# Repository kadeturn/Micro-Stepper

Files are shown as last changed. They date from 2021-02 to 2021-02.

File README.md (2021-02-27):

# Micro Stepper

This repository contains work on various breakout boards for the micro linear stepper motors used in motorised mobile phone cameras.

These stepper motors are available in several variations from different Chinese suppliers.

Current and future CAD models for the stepper motors can be found [here](hw/cad).

All PCBs are created using KiCad Nightly builds.

---

## Micro Breakout

The first breakout board is based on [this](https://www.aliexpress.com/item/4000616045699.html?spm=a2g0s.12269583.0.0.51854815RwJf8O) stepper motor from Aliexpress.

Both the Model A and Model B variants work with this breakout (the only difference being their linear guide mounting features).
These motors can produce a force in the range of ~100-150gf, the main downside is that they have quite a bit of backlash.

<p align="center">
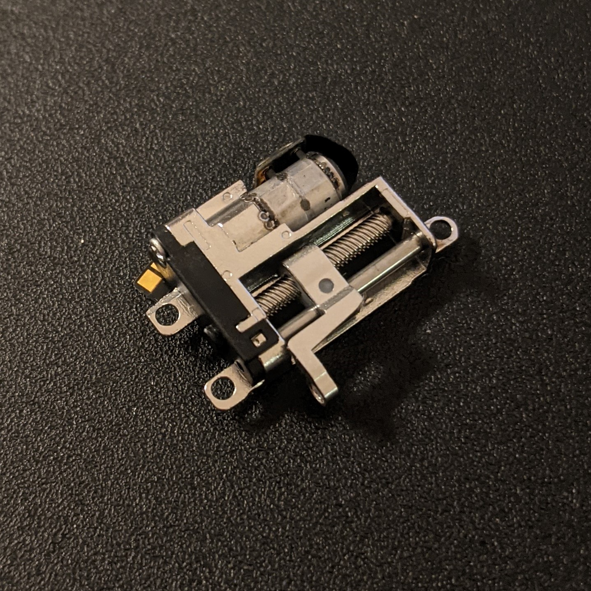
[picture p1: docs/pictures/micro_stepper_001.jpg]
  
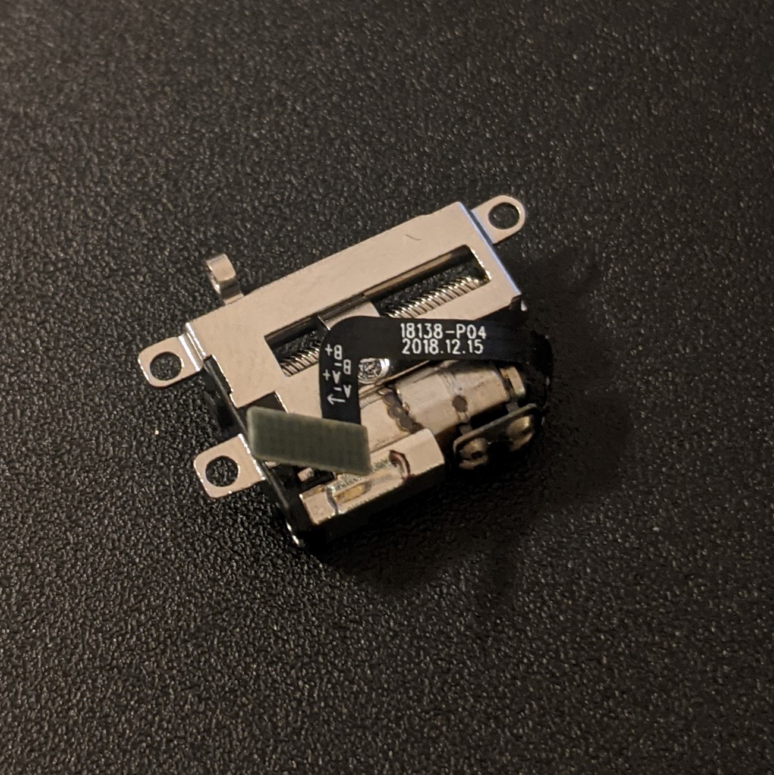
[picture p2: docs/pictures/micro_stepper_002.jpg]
  
</p>

The breakout uses the [Trinamic TMC2300](https://www.trinamic.com/products/integrated-circuits/details/tmc2300-la/) low voltage stepper motor driver. 

Both step/direction and UART based control are possible, with the latter enabling current sensing (useful for end stop detection).

The UART is single wire based, so an additional external resistor is required to split TX & RX out separately (more to come on that later).

<p align="center">
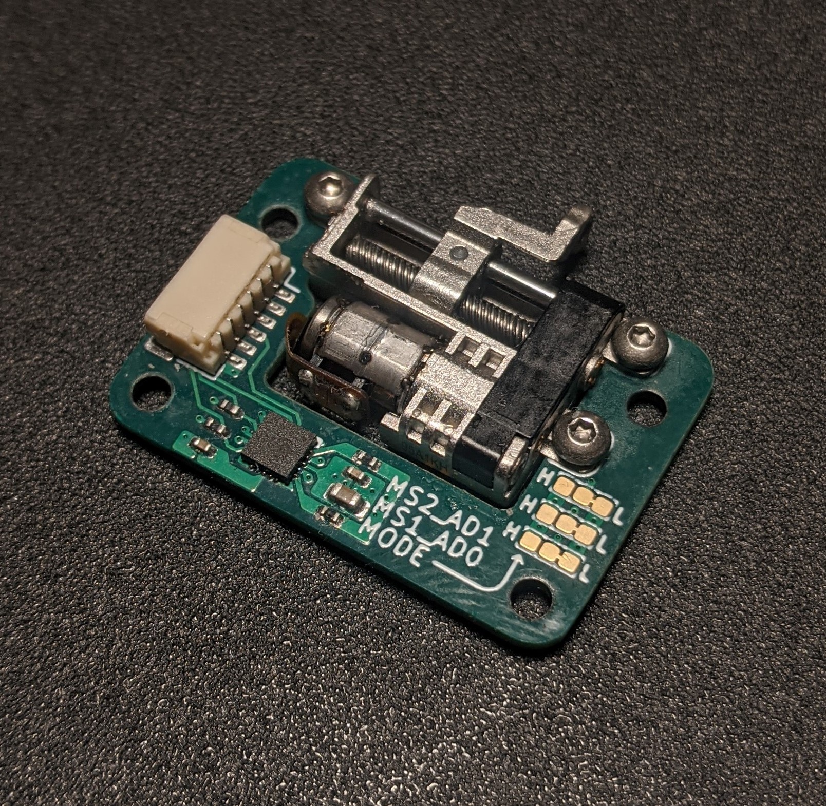
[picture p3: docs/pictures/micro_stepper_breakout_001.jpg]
  
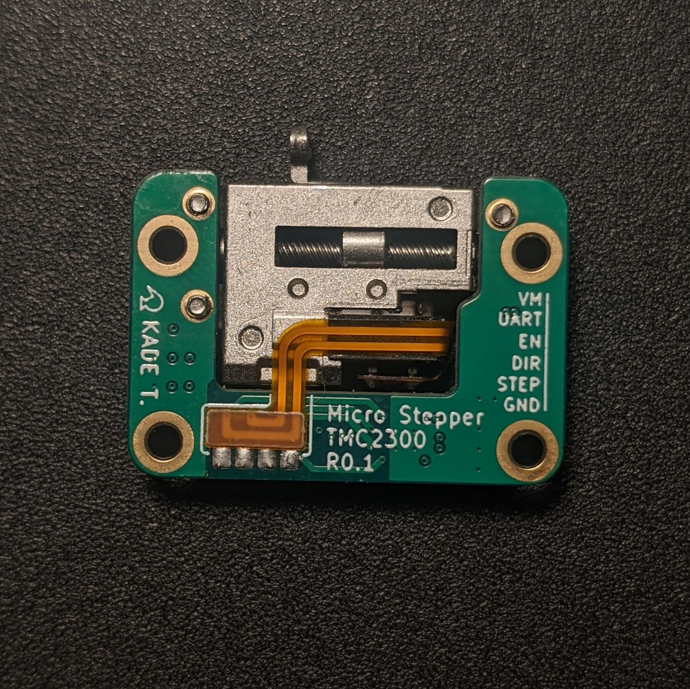
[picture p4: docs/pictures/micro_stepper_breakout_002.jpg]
  
</p>

KiCad and Gerber files are located [here](hw/micro_breakout_001).

---

## Micro Driver

The World's smallest stepper driver board (probably).

Based on the same TMC2300 stepper motor driver as used in the Micro Breakout. It's designed for use with any small low voltage stepper motor.

**The PCB is just 10.2mm x 6mm!!**

<p align="center">
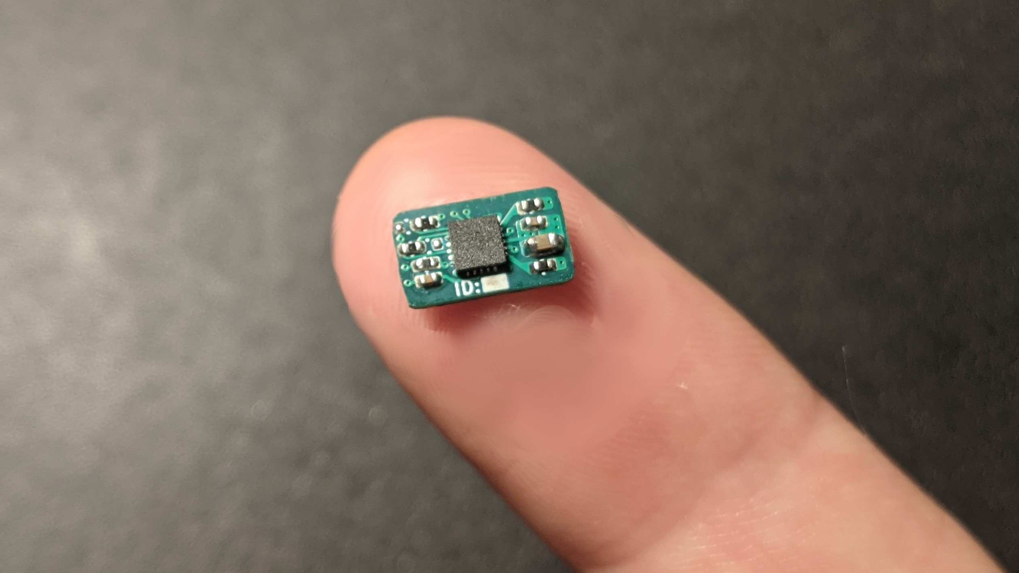
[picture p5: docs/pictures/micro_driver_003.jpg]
    
</p>

<p align="center">
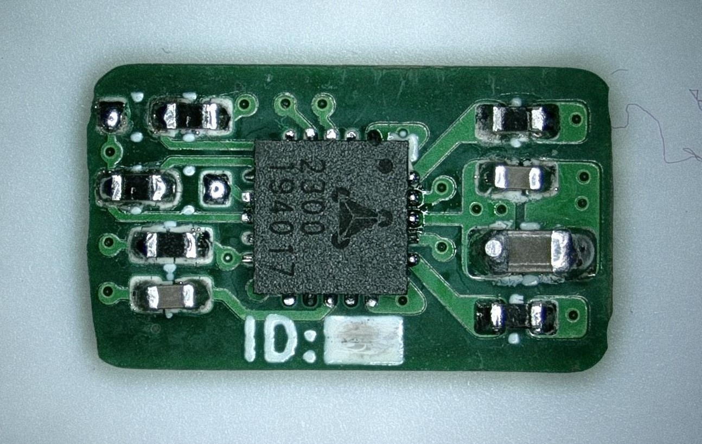
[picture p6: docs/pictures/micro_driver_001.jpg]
    
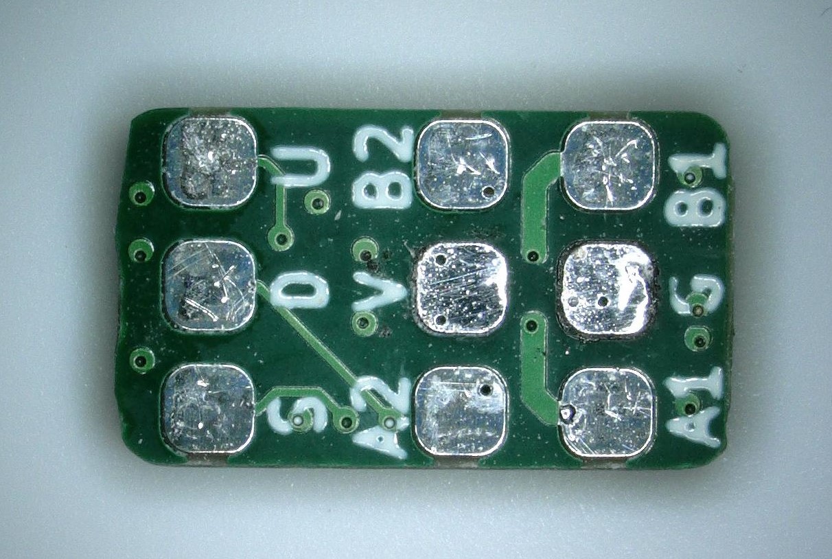
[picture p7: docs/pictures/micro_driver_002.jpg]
    
</p>

Due to a small issue with the enable pin always pulled low, and incorrect silkscreen, the files are currently not released (wait for rev002).

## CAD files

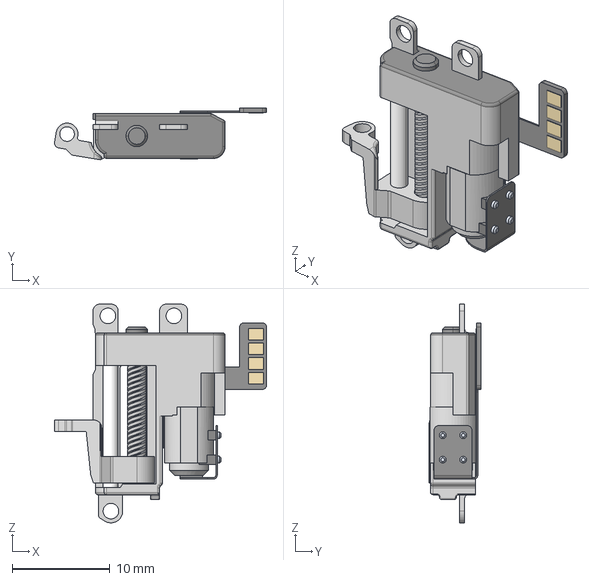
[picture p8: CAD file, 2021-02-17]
hw/cad/micro_stepper_asm.stp
21.7 x 5.29 x 22.4 mm
MICRO_STEPPER_BASE
STEPPER_SLIDER

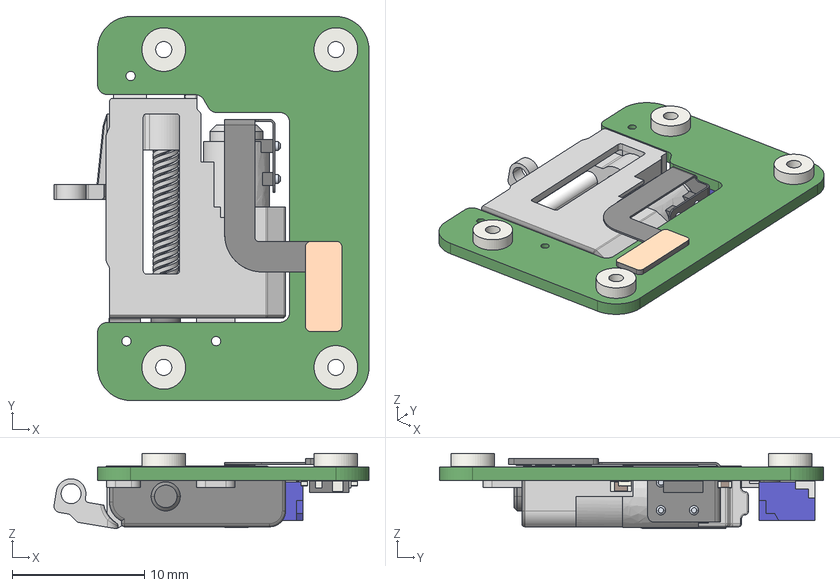
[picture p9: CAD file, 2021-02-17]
hw/micro_breakout_001/Export/micro_breakout_001.step
23.8 x 29.0 x 5.69 mm

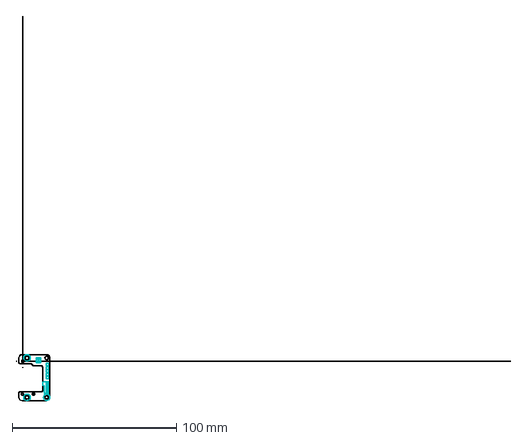
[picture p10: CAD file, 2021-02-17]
hw/micro_breakout_001/pcb_outline_001.dxf
301.0 x 234.0 mm

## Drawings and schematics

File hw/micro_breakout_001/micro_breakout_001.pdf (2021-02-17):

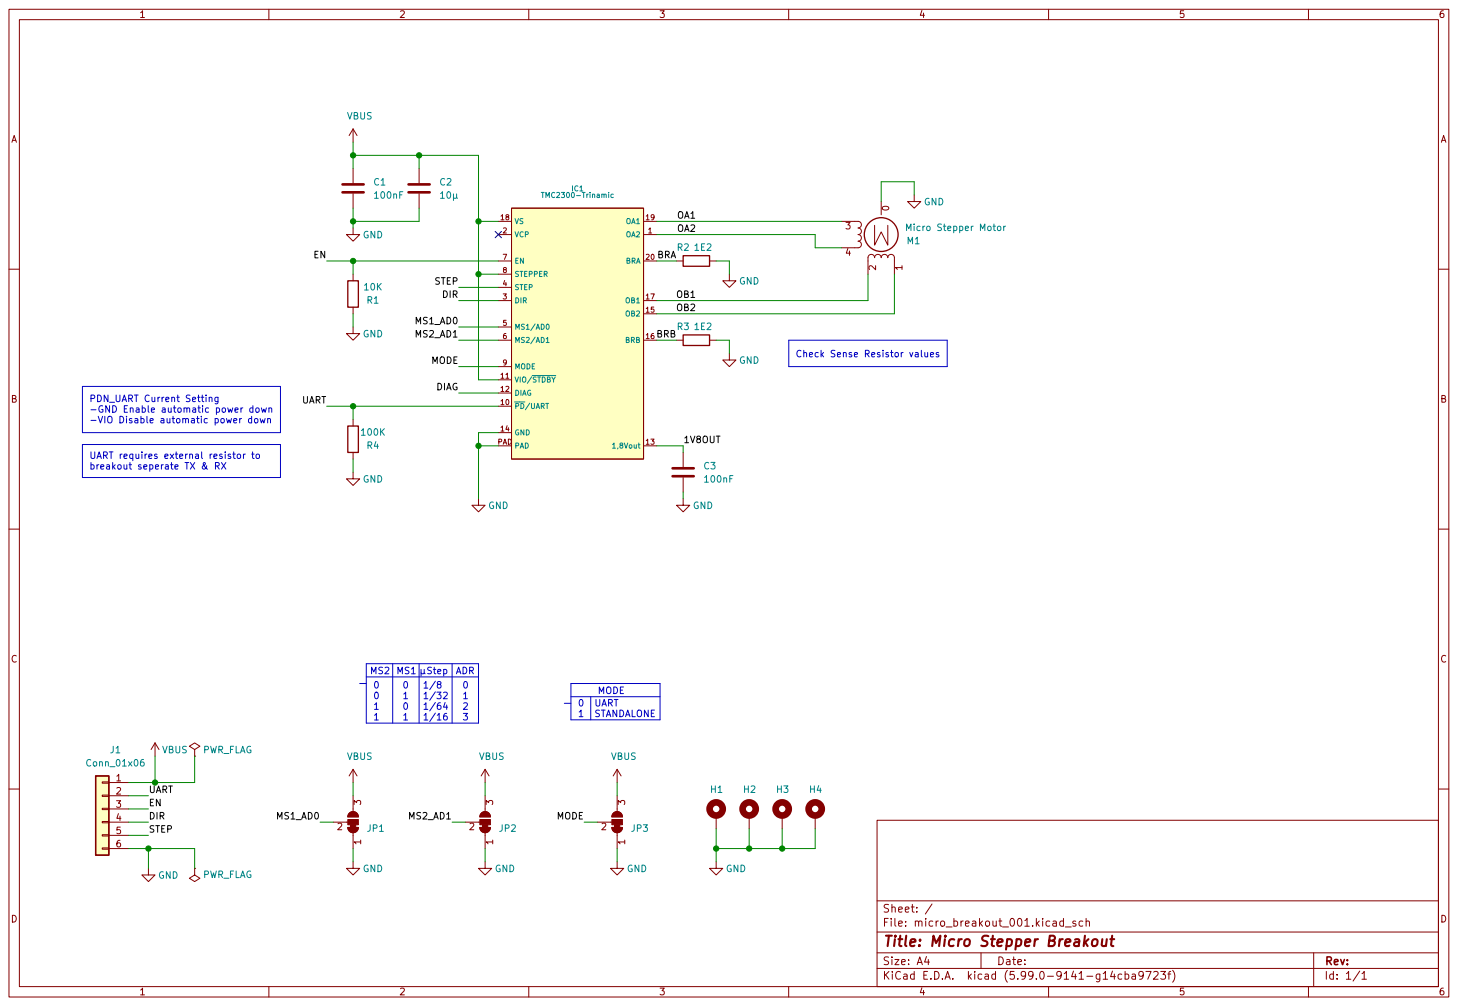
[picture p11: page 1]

OB2 MODE UART PDN_UART Current Setting

-GND Enable automatic power down

breakout seperate TX & RX

0 1 | UART STANDALONE

File: micro_breakout_001.kicad_sch Sheet: /
Id: 1/1 Title: Micro Stepper Breakout

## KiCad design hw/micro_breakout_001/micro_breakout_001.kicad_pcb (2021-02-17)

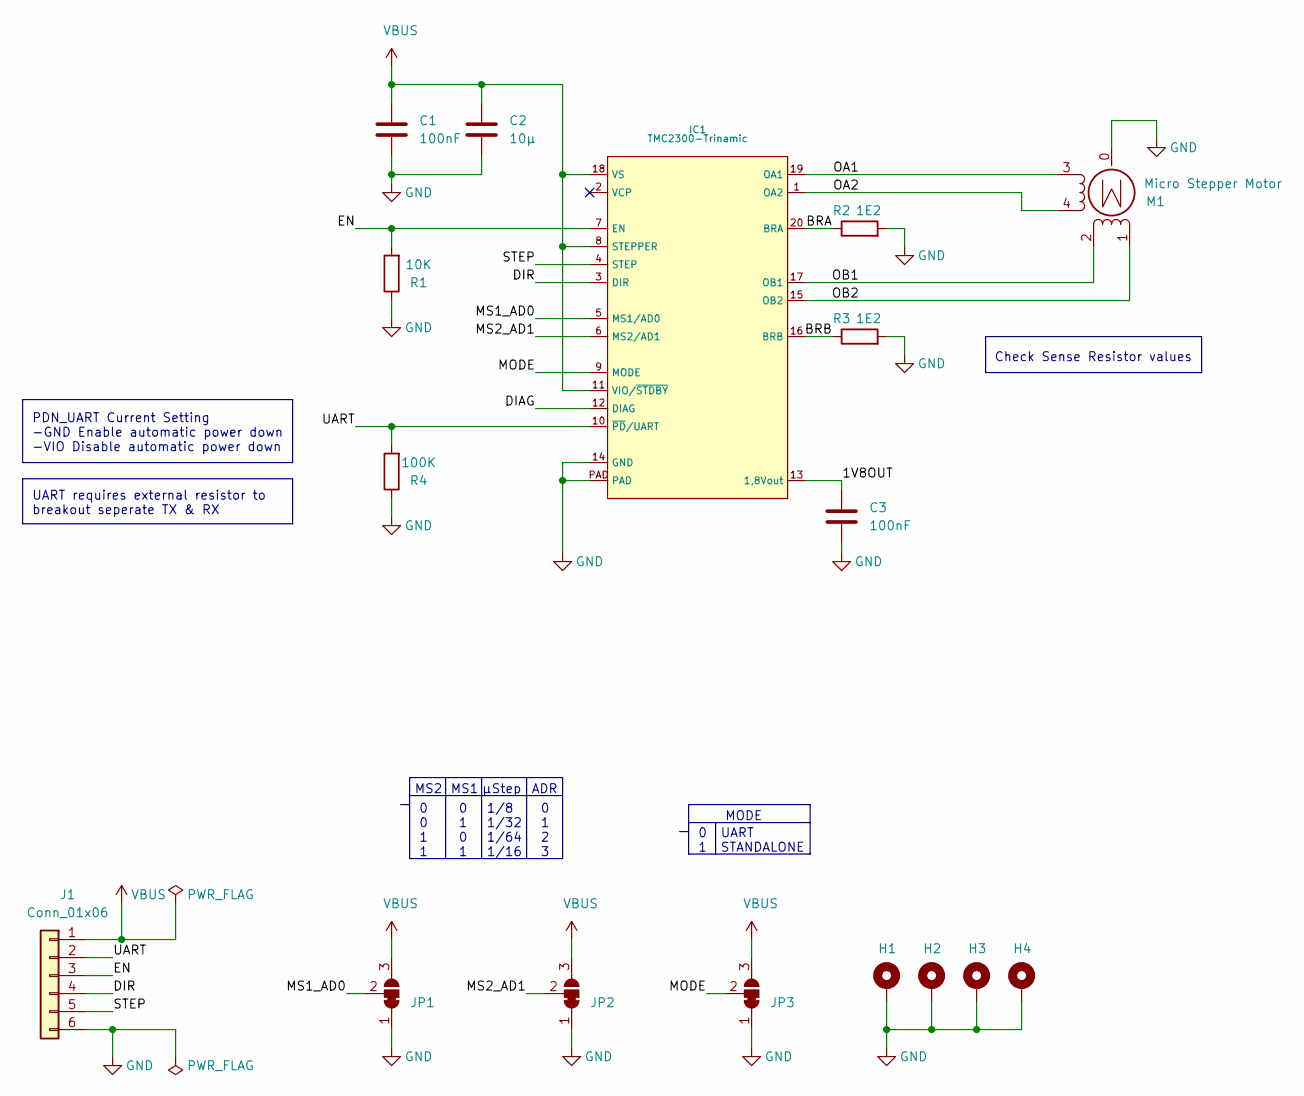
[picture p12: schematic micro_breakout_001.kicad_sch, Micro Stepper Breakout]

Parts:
C1, C3: 100nF; C_0402_1005Metric
C2: 10µ; C_0603_1608Metric
H1, H2, H3, H4: MountingHole; Mounting_Wuerth_WA-SMSI-M1.6_H1mm_9774010633
IC1: TMC2300-Trinamic; QFN20
J1: Conn_01x06; JST_SH_SM06B-SRSS-TB_1x06-1MP_P1.00mm_Horizontal
JP1, JP2, JP3: SolderJumper_3_Bridged12; J_NCNO_0903_20
M1: Micro Stepper Motor; Micro_Stepper
R1: 10K; R_0402_1005Metric
R2, R3: 1E2; R_0402_1005Metric
R4: 100K; R_0402_1005Metric

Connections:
/1V8OUT: C3.1, IC1.13 (1,8Vout)
/BRA: IC1.20 (BRA), R2.1
/BRB: IC1.16 (BRB), R3.1
/DIAG: IC1.12 (DIAG)
/DIR: IC1.3 (DIR), J1.4
/EN: IC1.7 (EN), J1.3, R1.2
/MODE: IC1.9 (MODE), JP3.2 (C)
/MS1_AD0: IC1.5 (MS1/AD0), JP1.2 (C)
/MS2_AD1: IC1.6 (MS2/AD1), JP2.2 (C)
/OA1: IC1.19 (OA1), M1.3
/OA2: IC1.1 (OA2), M1.4
/OB1: IC1.17 (OB1), M1.2 (-)
/OB2: IC1.15 (OB2), M1.1
/STEP: IC1.4 (STEP), J1.5
/UART: IC1.10 (~PD~/UART), J1.2, R4.2
GND: C1.2, C2.2, C3.2, H1.1, H2.1, H3.1, H4.1, IC1.14 (GND), IC1.PAD, J1.6, JP1.1 (A), JP2.1 (A), JP3.1 (A), M1.0 (Sheild), R1.1, R2.2, R3.2, R4.1
VBUS: C1.1, C2.1, IC1.8 (STEPPER), IC1.11 (VIO/~STDBY), IC1.18 (VS), J1.1, JP1.3 (B), JP2.3 (B), JP3.3 (B)

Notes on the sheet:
PDN_UART Current Setting -GND Enable automatic power down -VIO Disable automatic power down
UART requires external resistor to breakout seperate TX & RX
MS2
0 0 1 1
MS1
0 1 0 1
µStep
1/8 1/32 1/64 1/16
ADR
0 1 2 3
0 1
UART STANDALONE
MODE
Check Sense Resistor values

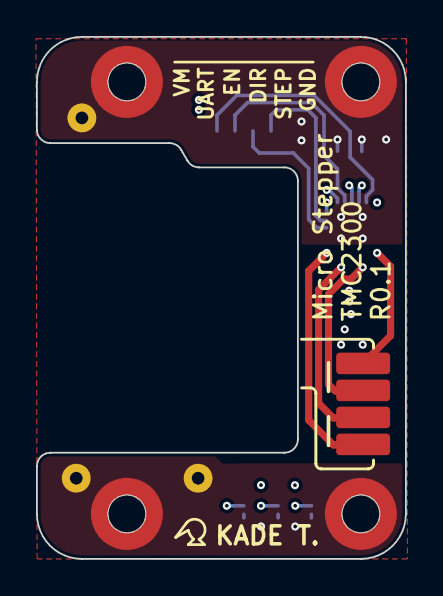
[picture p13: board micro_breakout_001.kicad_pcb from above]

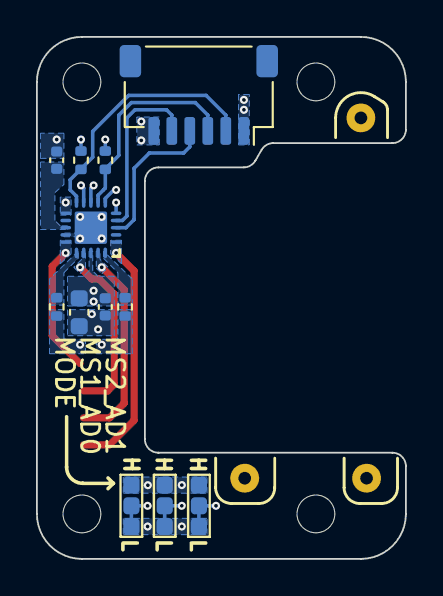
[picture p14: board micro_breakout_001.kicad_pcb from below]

Board: 4 copper layers, 20.5 x 29.0 mm, 17 parts (13 on the bottom side), 16 nets.

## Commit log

2021-02-17 Commit stepper motor CAD model
    [micro_stepper_asm.stp]
2021-02-17 Add Micro Breakout KiCad files
    [micro_breakout_001.kicad_pcb, micro_breakout_001.kicad_sch, micro_breakout_001.step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]
2021-02-18 Update README.md Add micro driver finger picture
    Update README.md
    Readme updated
    Readme updated
